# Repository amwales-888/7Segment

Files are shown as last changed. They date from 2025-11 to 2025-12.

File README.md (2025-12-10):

# 7Segment
Simple Large 7Segment Display

Who doesn't love big 7Segment displays?
Modelled the hardware in solidworks, printed on BambuLabs P1S. PCBs designed in KiCAD and boards manufactured by JLPCB.
The microcontroller I am using is a dsPIC33CK and it is interfaced to the WS2812 chips through DMA->SPI. It took quite a bit of fiddling to get the DMA->SPI working. 
</p>
For the clock I used a battery backed ds3102, 3 button's allow you to set the time and change the colors.
</p>
<table>
  <tr>
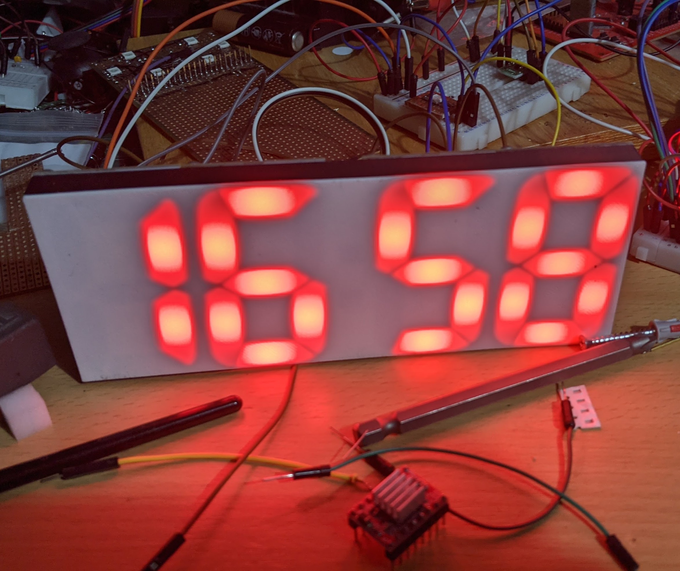
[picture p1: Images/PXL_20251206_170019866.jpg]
    <td> </td>
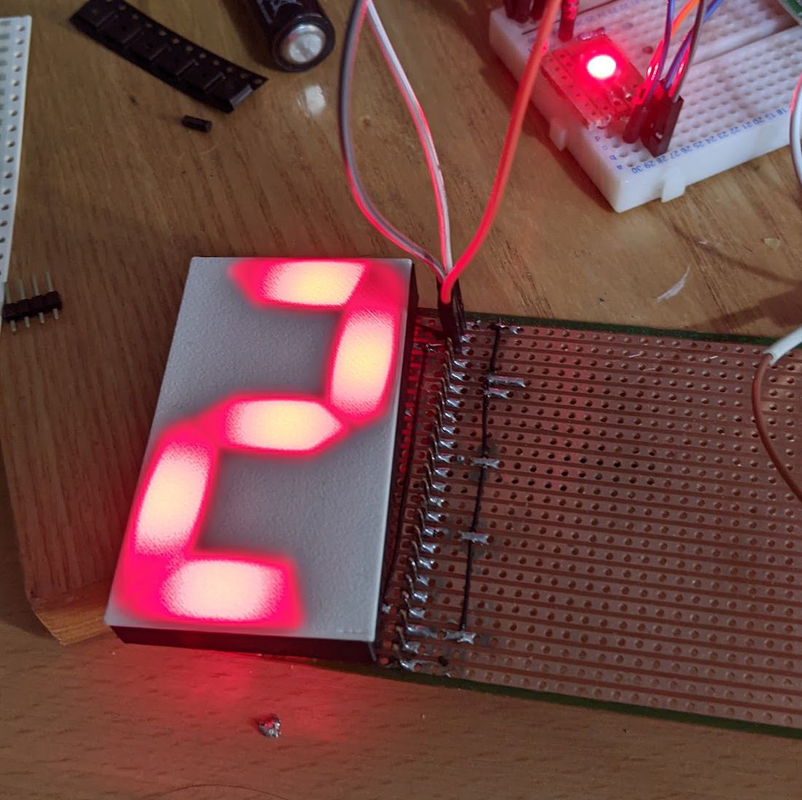
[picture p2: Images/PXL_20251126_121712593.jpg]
    <td> </td>
  </tr>
  <tr>
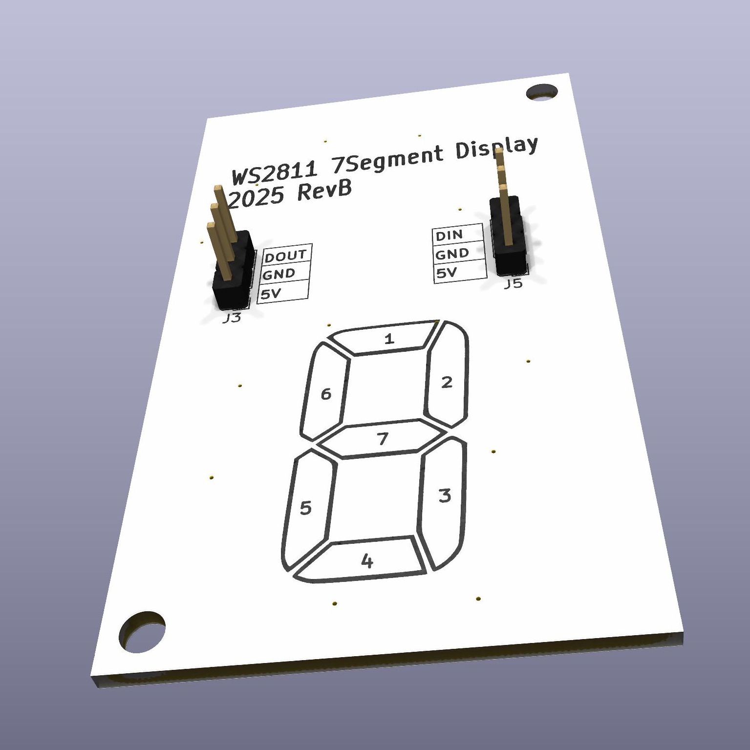
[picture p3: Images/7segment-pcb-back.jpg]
    <td> </td>
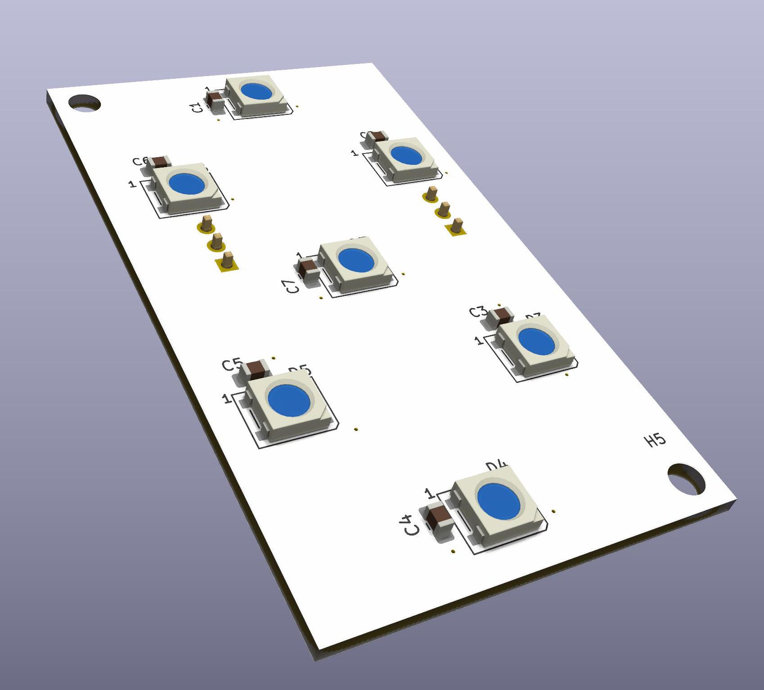
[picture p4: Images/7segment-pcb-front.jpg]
    <td> </td>
  </tr>
  <tr>
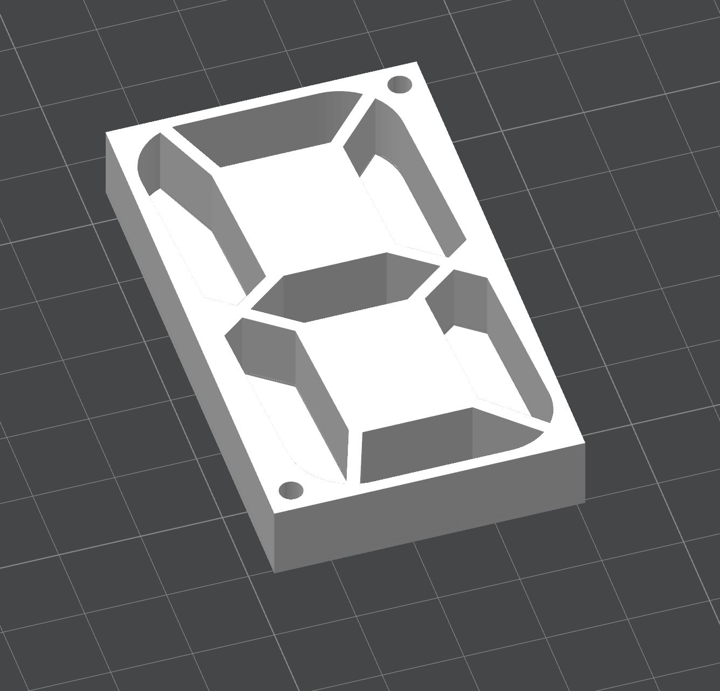
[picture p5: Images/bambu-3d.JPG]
    <td> </td>
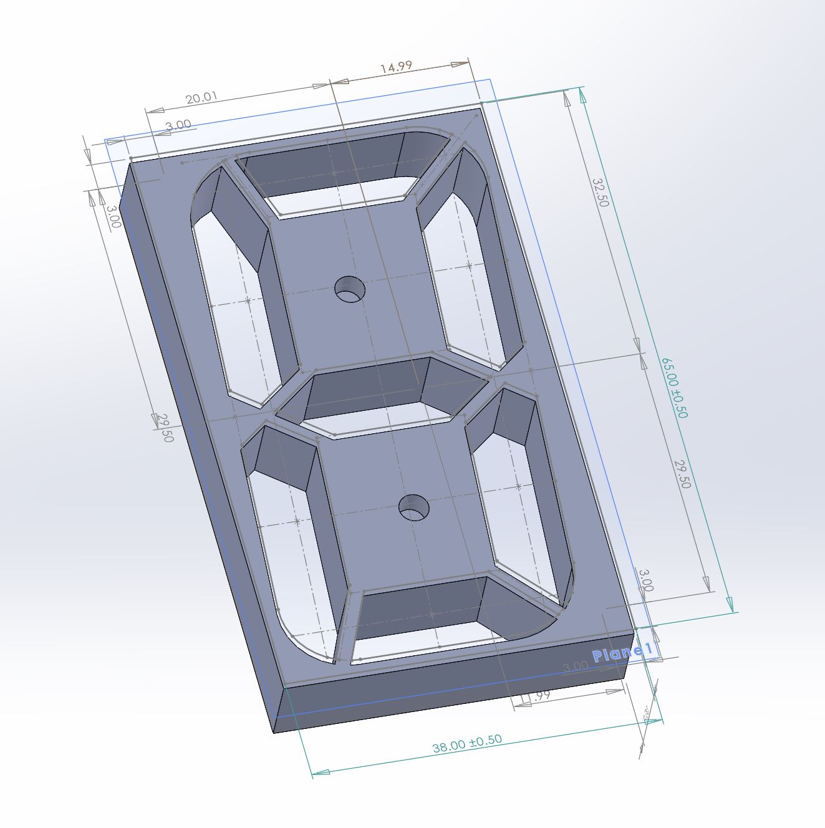
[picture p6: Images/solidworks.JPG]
    <td> </td>
  </tr>
</table>

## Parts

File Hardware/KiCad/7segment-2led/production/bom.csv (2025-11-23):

Designator | Footprint | Quantity | Value | LCSC Part #
C1, C2, C3, C4, C5, C6, C7 | 0805 | 7 | 0.1uF
D1, D2, D3, D4, D5, D6, D7 | LED_WS2812B_PLCC4_5.0x5.0mm_P3.2mm | 7 | WS2812B
J3, J5 | PinHeader_1x03_P2.54mm_Vertical | 2 | Conn_01x03

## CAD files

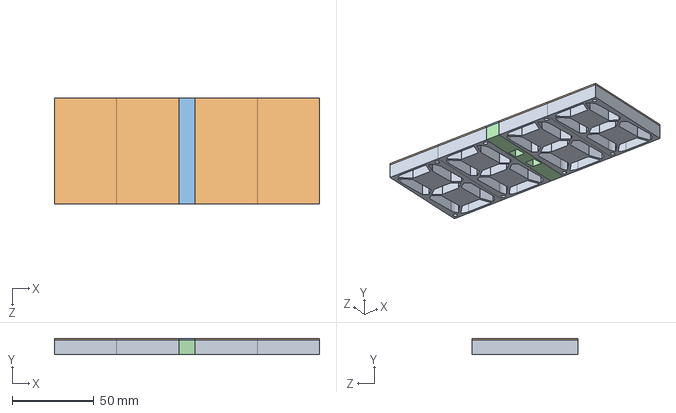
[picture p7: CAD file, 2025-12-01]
Hardware/CAD/7segment-assembley.STEP
162.0 x 10.0 x 65.0 mm
led-segment-p4 x 4

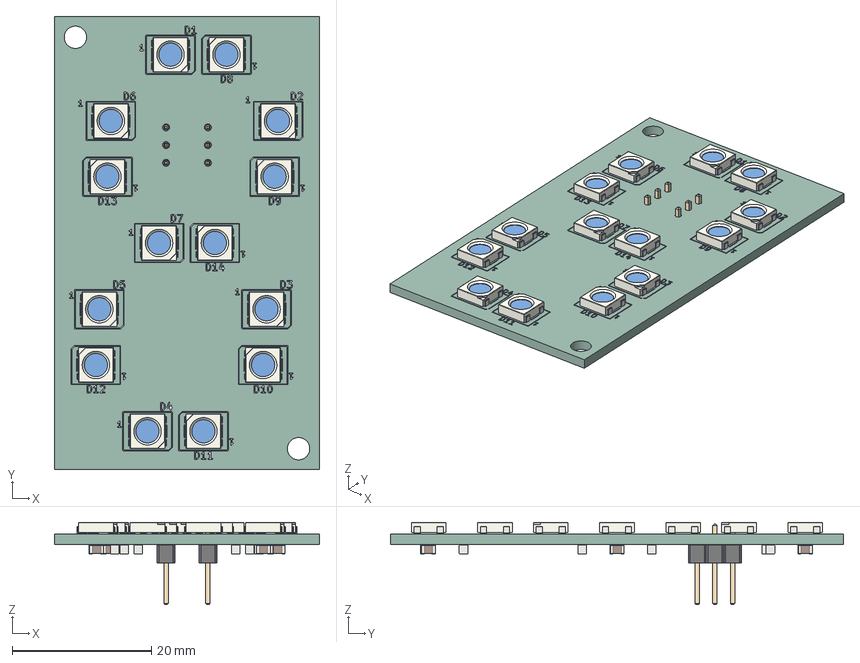
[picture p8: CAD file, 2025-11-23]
Hardware/KiCad/7segment-2led/7segment-2led.step
38.0 x 65.0 x 11.8 mm
LED_WS2812B_PLCC4_5.0x5.0mm_P3.2mm x 14
C_0805_2012Metric x 14
PinHeader_1x03_P2.54mm_Vertical x 2
7segment_silkscreen x 2
7segment_PCB

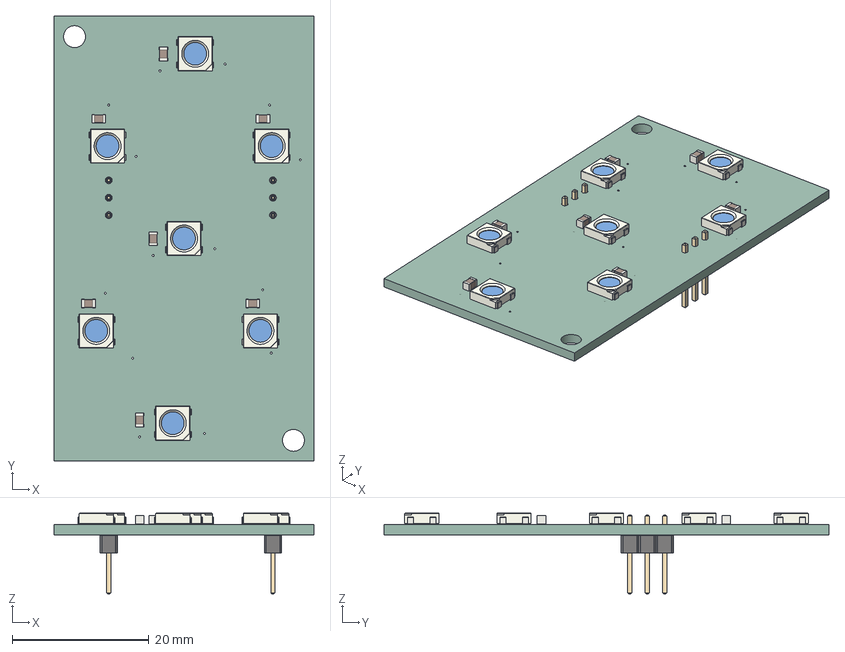
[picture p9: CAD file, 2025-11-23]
Hardware/KiCad/7segment/7segment.step
38.0 x 65.0 x 11.8 mm
LED_WS2812B_PLCC4_5.0x5.0mm_P3.2mm x 7
C_0805_2012Metric x 7
PinHeader_1x03_P2.54mm_Vertical x 2
7segment_PCB

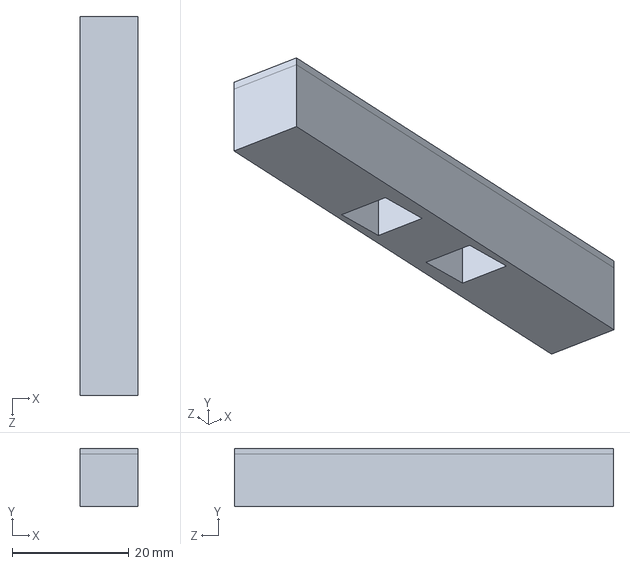
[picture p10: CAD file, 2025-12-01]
Hardware/CAD/Part1.SLDPRT
10.0 x 10.0 x 65.0 mm

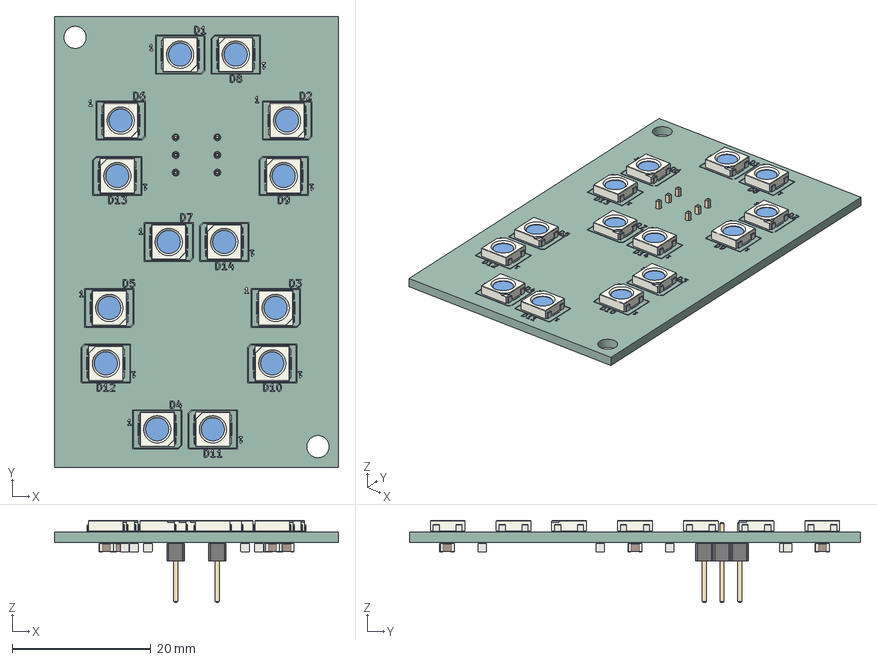
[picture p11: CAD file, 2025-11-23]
Hardware/KiCad/7segment-2led/7segment.step
41.0 x 65.0 x 11.8 mm
LED_WS2812B_PLCC4_5.0x5.0mm_P3.2mm x 14
C_0805_2012Metric x 14
PinHeader_1x03_P2.54mm_Vertical x 2
7segment_silkscreen x 2
7segment_PCB

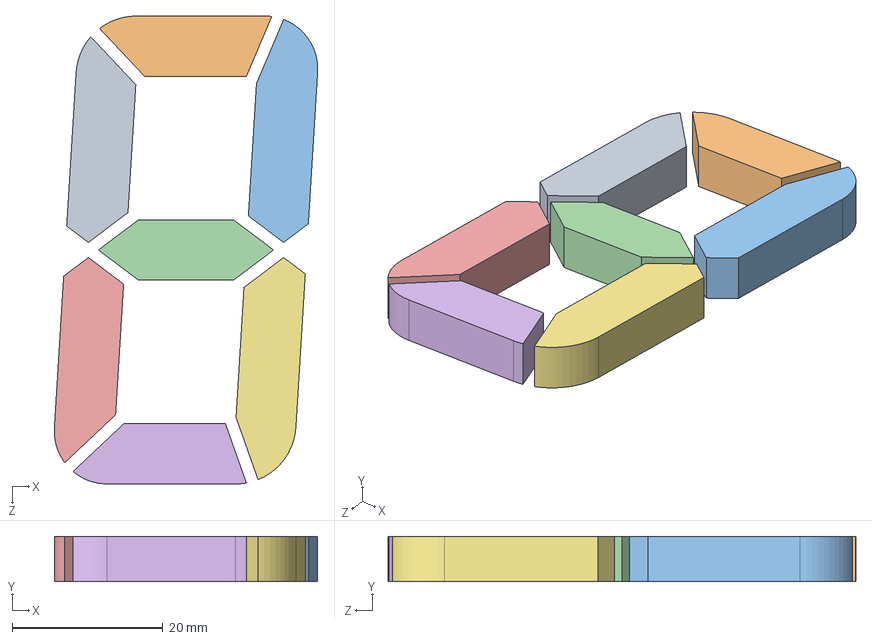
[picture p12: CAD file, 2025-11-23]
Hardware/CAD/led-segment-insert-p4.STEP
34.9 x 6.00 x 62.0 mm

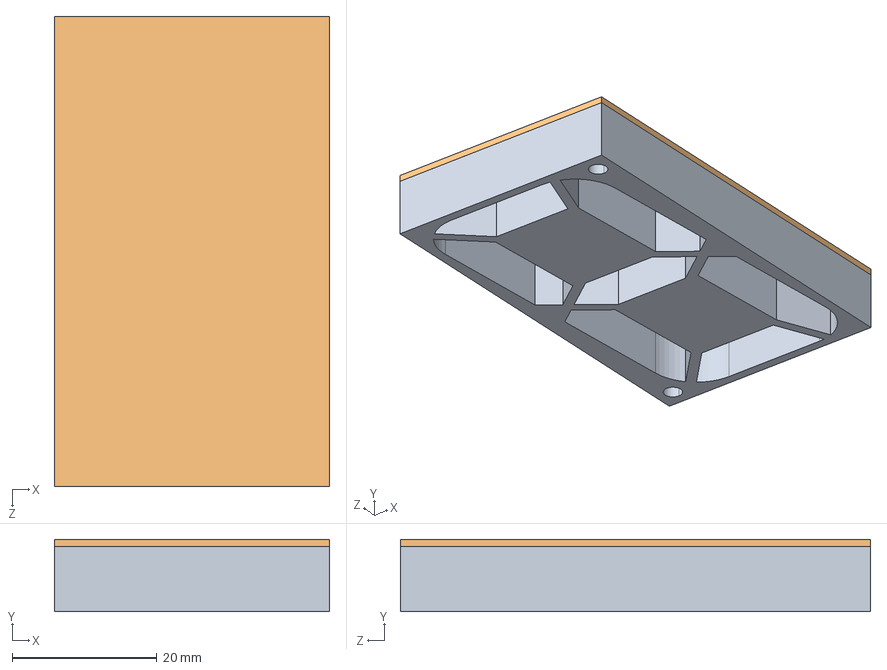
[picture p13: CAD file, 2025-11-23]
Hardware/CAD/led-segment-p4.STEP
38.0 x 10.0 x 65.0 mm

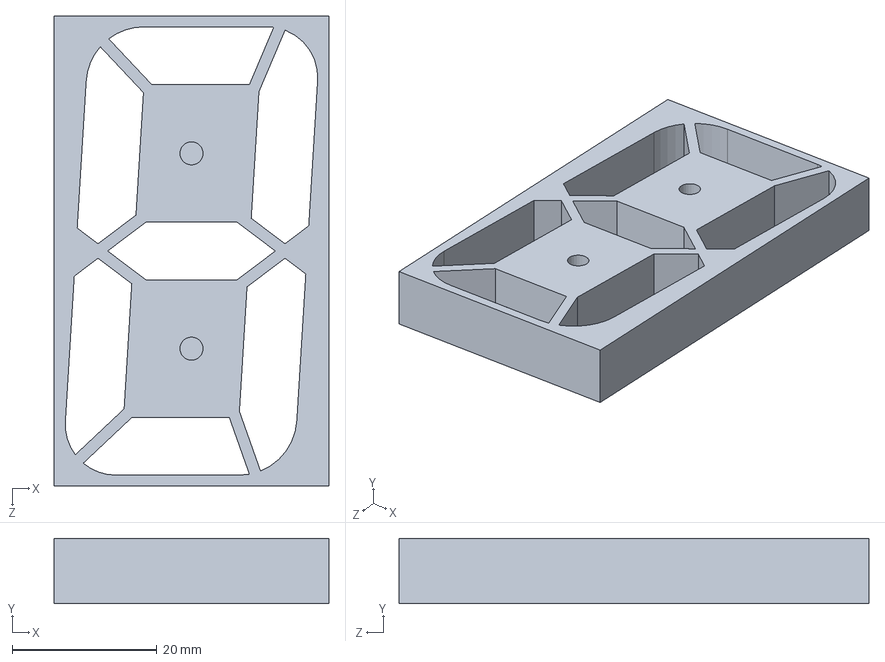
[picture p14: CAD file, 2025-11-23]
Hardware/CAD/led-segment-2led-p4.SLDPRT
38.0 x 9.00 x 65.0 mm

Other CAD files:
Hardware/CAD/led-segment-p3.SLDPRT
Hardware/CAD/7segment-assembley.SLDASM
Hardware/CAD/led-segment-insert-p4.SLDPRT
Hardware/CAD/led-segment-p4.SLDPRT

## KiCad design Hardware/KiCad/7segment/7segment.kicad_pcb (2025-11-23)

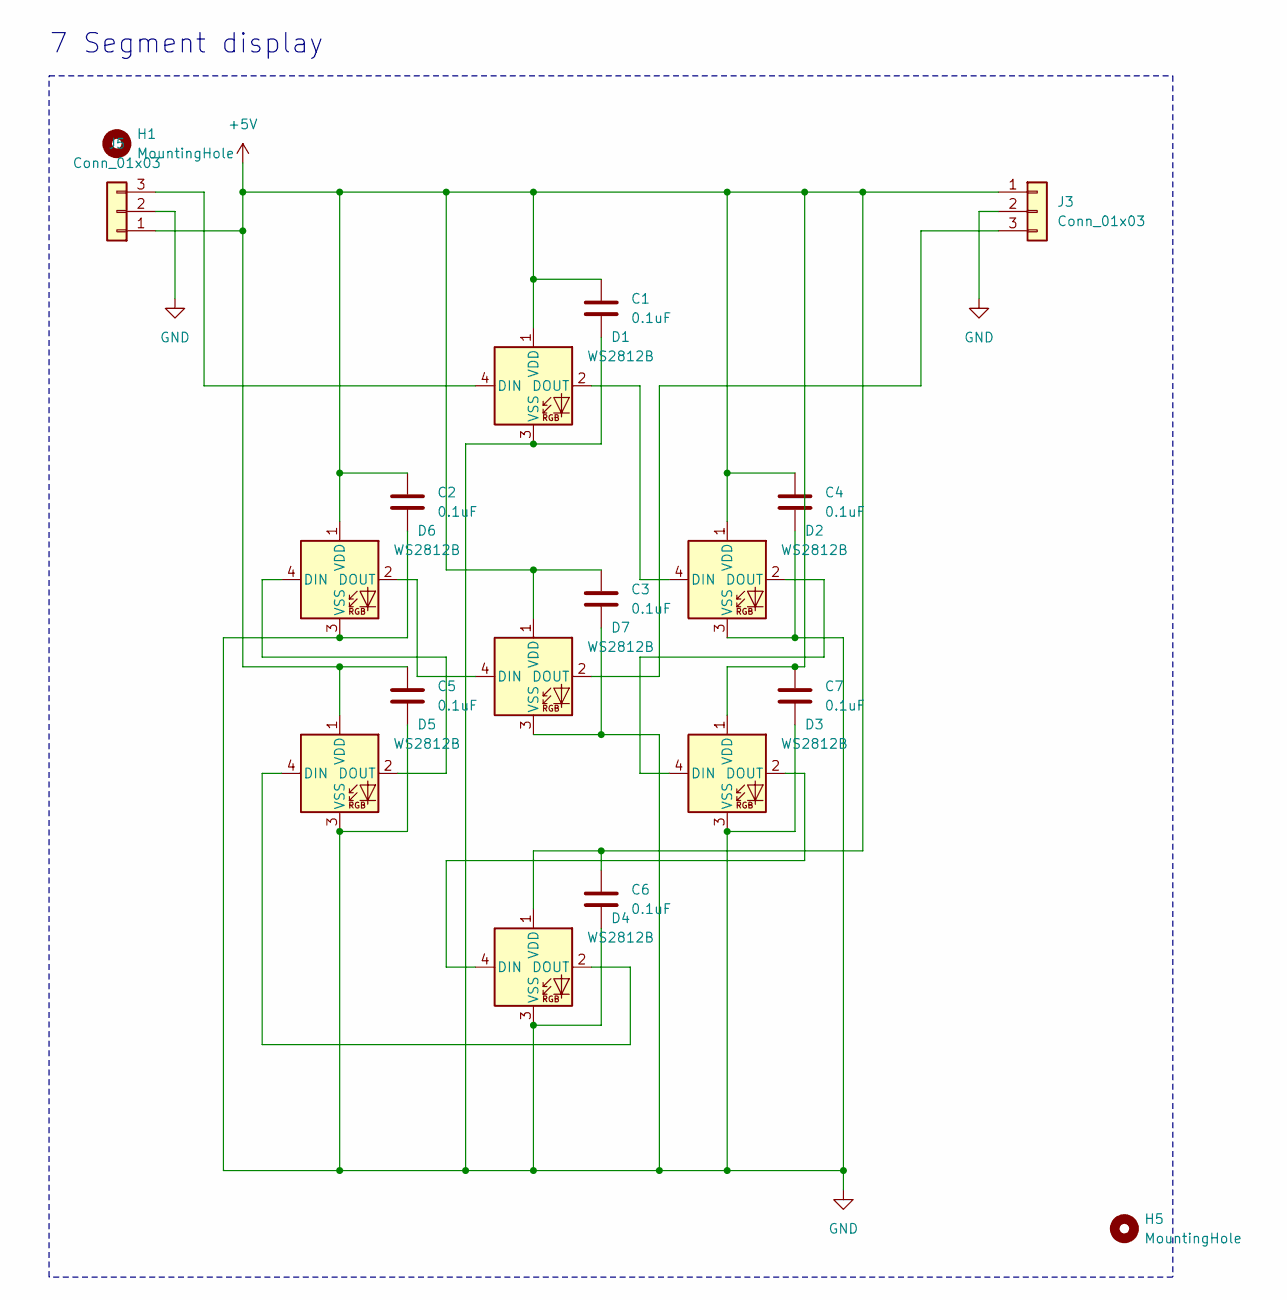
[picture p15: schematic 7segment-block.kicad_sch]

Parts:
C1, C2, C3, C4, C5, C6, C7: 0.1uF; C_0805_2012Metric_Pad1.18x1.45mm_HandSolder
D1, D2, D3, D4, D5, D6, D7: WS2812B; LED_WS2812B_PLCC4_5.0x5.0mm_P3.2mm
H1, H5: MountingHole; MountingHole_3.2mm_M3
J3, J5: Conn_01x03; PinHeader_1x03_P2.54mm_Vertical

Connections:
+5V: C1.1, C2.1, C3.1, C4.1, C5.1, C6.1, C7.1, D1.1 (VDD), D2.1 (VDD), D3.1 (VDD), D4.1 (VDD), D5.1 (VDD), D6.1 (VDD), D7.1 (VDD), J3.1, J5.1
GND: C1.2, C2.2, C3.2, C4.2, C5.2, C6.2, C7.2, D1.3 (VSS), D2.3 (VSS), D3.3 (VSS), D4.3 (VSS), D5.3 (VSS), D6.3 (VSS), D7.3 (VSS), J3.2, J5.2
unnamed: D1.4 (DIN), J5.3
unnamed: D1.2 (DOUT), D2.4 (DIN)
unnamed: D2.2 (DOUT), D3.4 (DIN)
unnamed: D3.2 (DOUT), D4.4 (DIN)
unnamed: D4.2 (DOUT), D5.4 (DIN)
unnamed: D5.2 (DOUT), D6.4 (DIN)
unnamed: D6.2 (DOUT), D7.4 (DIN)
unnamed: D7.2 (DOUT), J3.3

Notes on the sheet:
7 Segment display

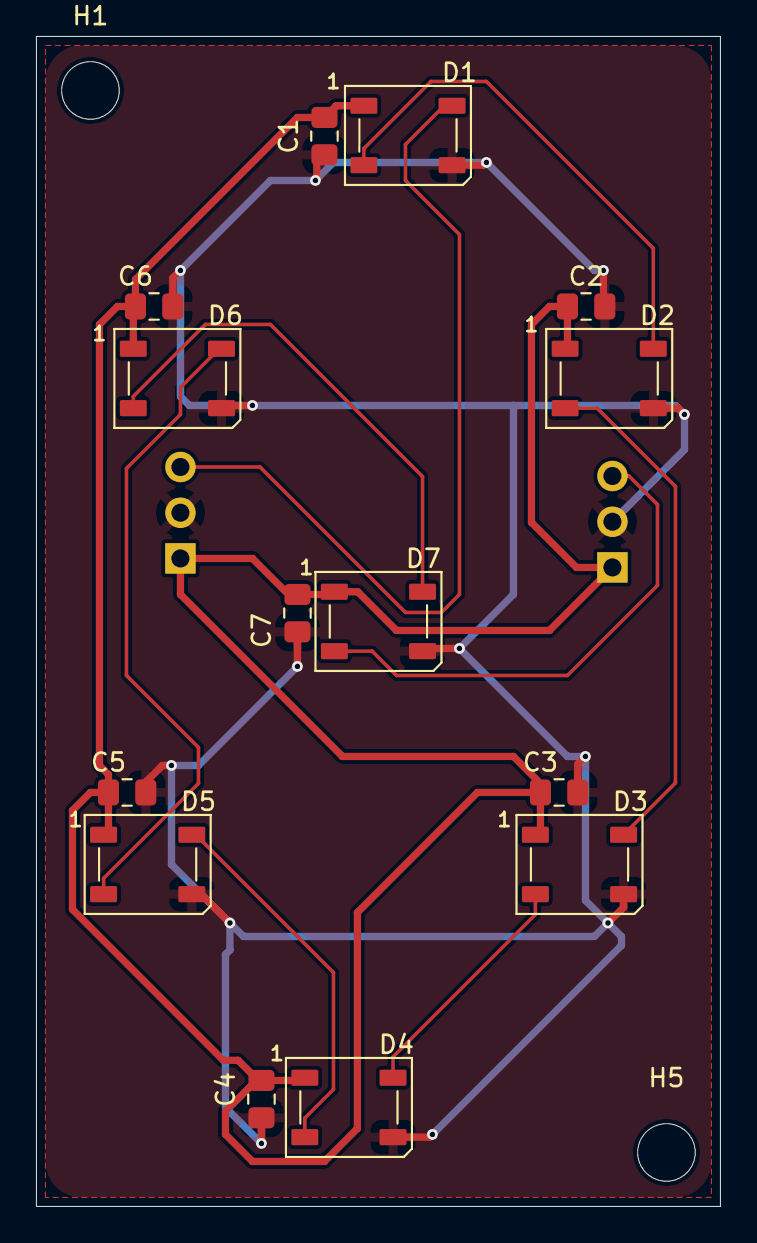
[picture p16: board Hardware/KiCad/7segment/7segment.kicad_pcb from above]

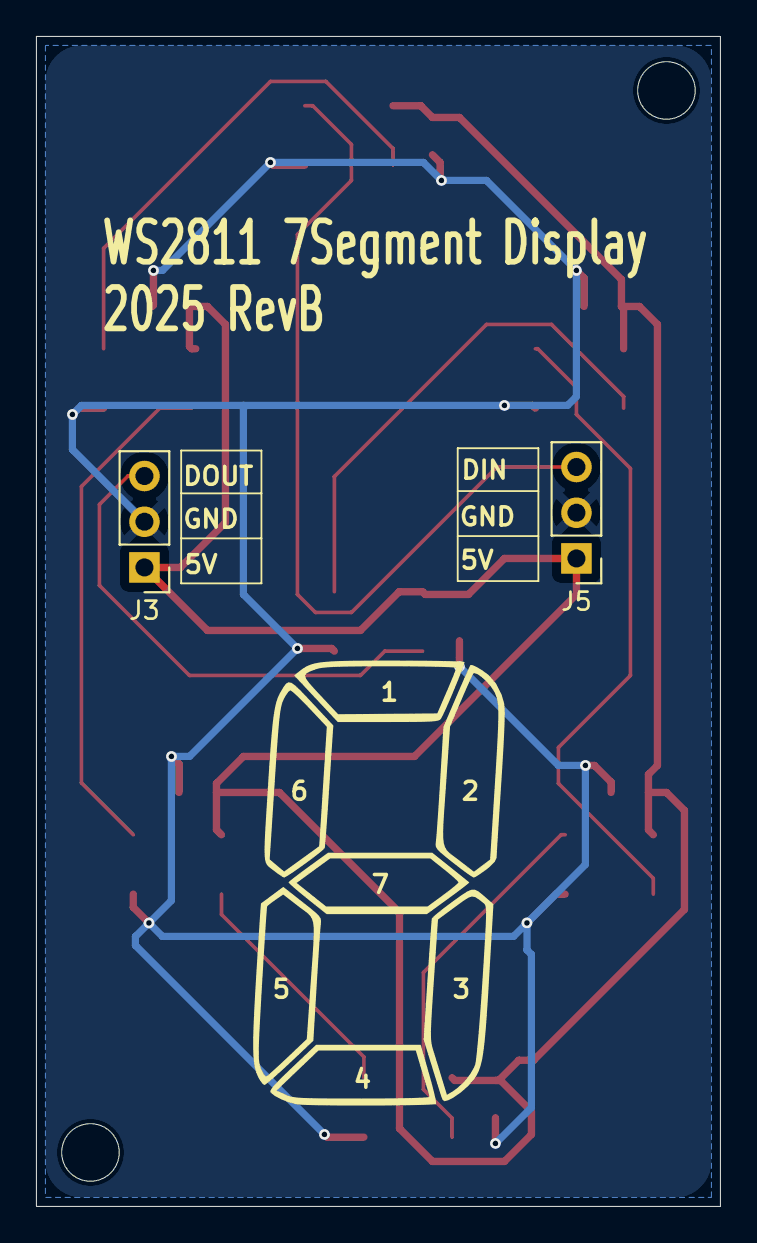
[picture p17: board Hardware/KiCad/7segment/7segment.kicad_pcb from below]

Board: 2 copper layers, 38.0 x 65.0 mm, 18 parts (2 on the bottom side), 10 nets.

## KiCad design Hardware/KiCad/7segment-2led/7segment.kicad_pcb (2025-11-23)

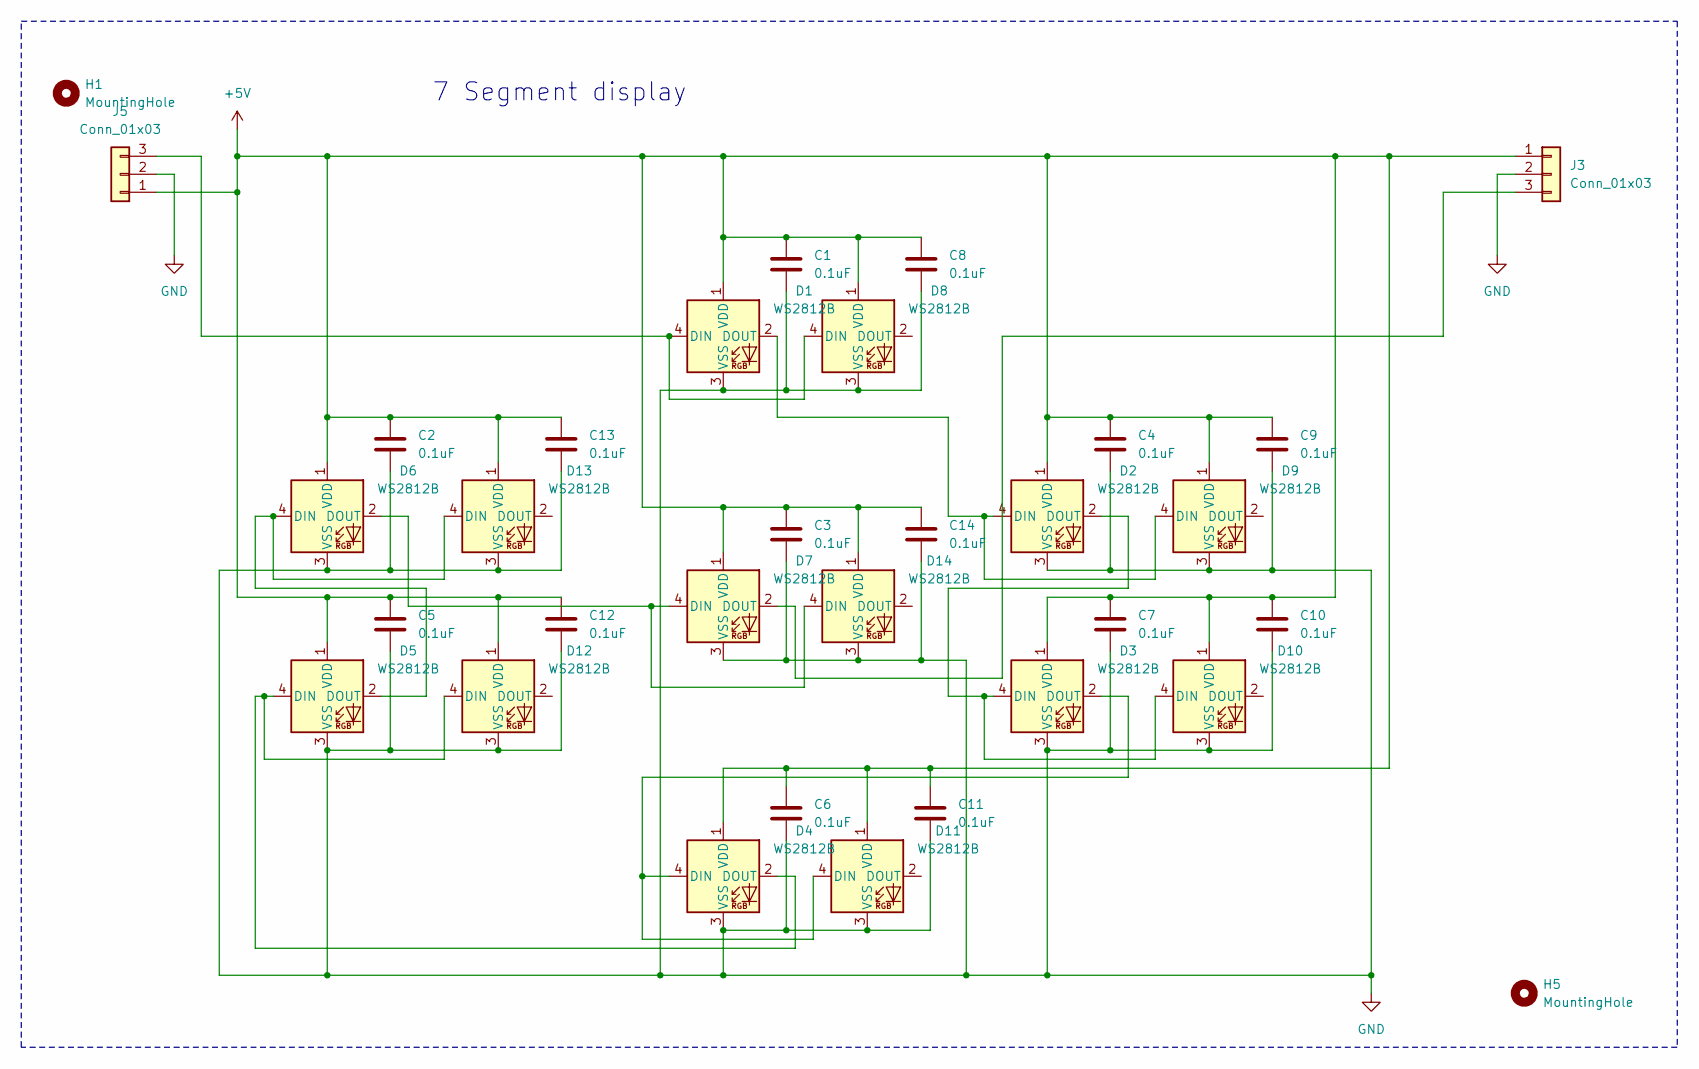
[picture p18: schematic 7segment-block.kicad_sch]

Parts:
C1, C2, C3, C4, C5, C6, C7, C8, C9, C10, C11, C12, C13, C14: 0.1uF; C_0805_2012Metric_Pad1.18x1.45mm_HandSolder
D1, D2, D3, D4, D5, D6, D7, D8, D9, D10, D11, D12, D13, D14: WS2812B; LED_WS2812B_PLCC4_5.0x5.0mm_P3.2mm
H1, H5: MountingHole; MountingHole_3.2mm_M3
J3, J5: Conn_01x03; PinHeader_1x03_P2.54mm_Vertical

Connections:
+5V: C1.1, C2.1, C3.1, C4.1, C5.1, C6.1, C7.1, C8.1, C9.1, C10.1, C11.1, C12.1, C13.1, C14.1, D1.1 (VDD), D2.1 (VDD), D3.1 (VDD), D4.1 (VDD), D5.1 (VDD), D6.1 (VDD), D7.1 (VDD), D8.1 (VDD), D9.1 (VDD), D10.1 (VDD), D11.1 (VDD), D12.1 (VDD), D13.1 (VDD), D14.1 (VDD), J3.1, J5.1
GND: C1.2, C2.2, C3.2, C4.2, C5.2, C6.2, C7.2, C8.2, C9.2, C10.2, C11.2, C12.2, C13.2, C14.2, D1.3 (VSS), D2.3 (VSS), D3.3 (VSS), D4.3 (VSS), D5.3 (VSS), D6.3 (VSS), D7.3 (VSS), D8.3 (VSS), D9.3 (VSS), D10.3 (VSS), D11.3 (VSS), D12.3 (VSS), D13.3 (VSS), D14.3 (VSS), J3.2, J5.2
unnamed: D1.4 (DIN), D8.4 (DIN), J5.3
unnamed: D1.2 (DOUT), D2.4 (DIN), D9.4 (DIN)
unnamed: D7.2 (DOUT), J3.3
unnamed: D2.2 (DOUT), D3.4 (DIN), D10.4 (DIN)
unnamed: D3.2 (DOUT), D4.4 (DIN), D11.4 (DIN)
unnamed: D4.2 (DOUT), D5.4 (DIN), D12.4 (DIN)
unnamed: D5.2 (DOUT), D6.4 (DIN), D13.4 (DIN)
unnamed: D6.2 (DOUT), D7.4 (DIN), D14.4 (DIN)

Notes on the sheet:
7 Segment display

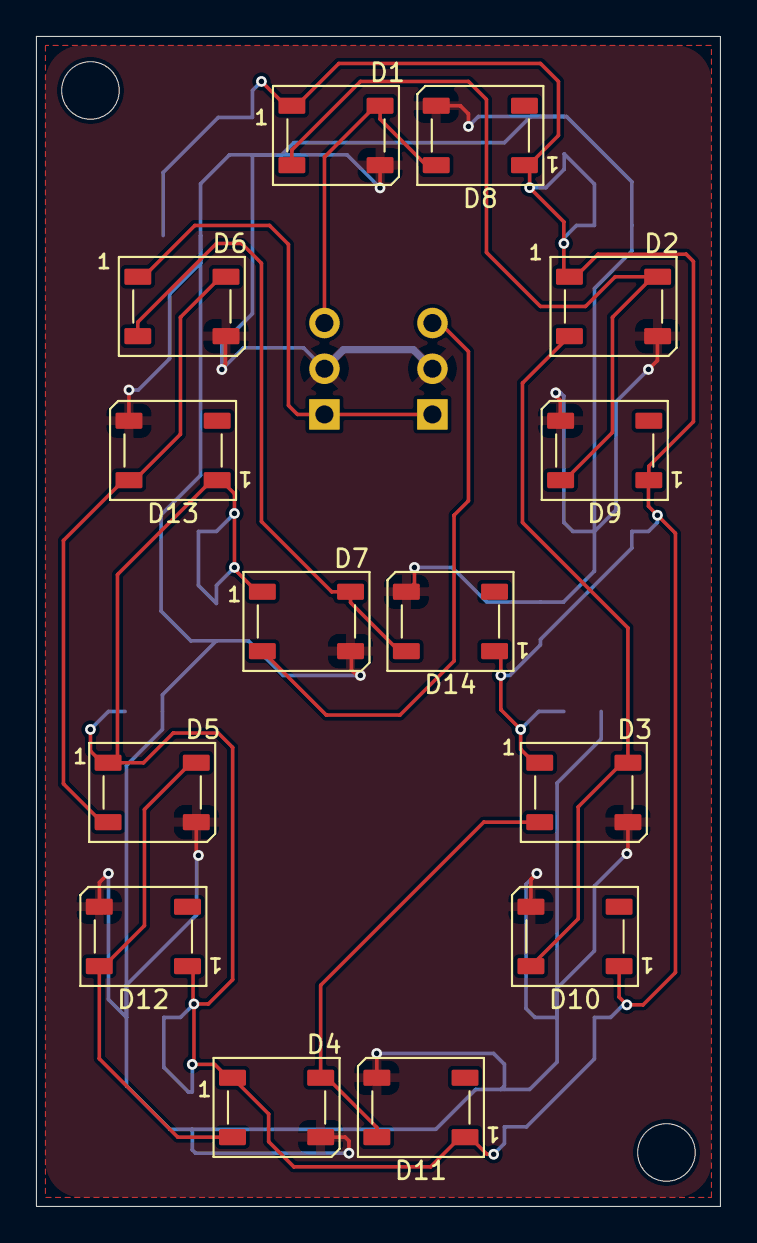
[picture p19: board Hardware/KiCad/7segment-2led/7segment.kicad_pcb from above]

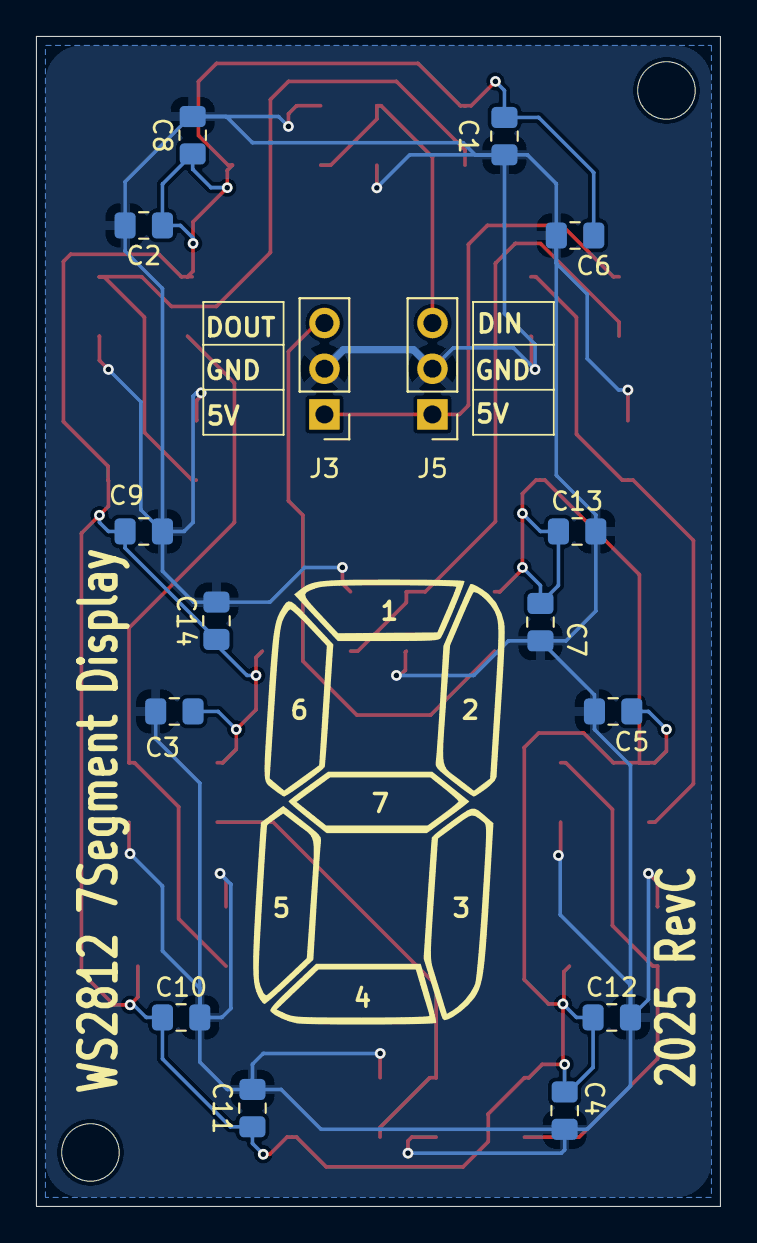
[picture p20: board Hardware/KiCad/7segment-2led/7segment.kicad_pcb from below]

Board: 2 copper layers, 38.0 x 65.0 mm, 32 parts (16 on the bottom side), 10 nets.

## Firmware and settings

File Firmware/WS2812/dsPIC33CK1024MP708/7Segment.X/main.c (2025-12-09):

/*
© [2025] Microchip Technology Inc. and its subsidiaries.

    Subject to your compliance with these terms, you may use Microchip 
    software and any derivatives exclusively with Microchip products. 
    You are responsible for complying with 3rd party license terms  
    applicable to your use of 3rd party software (including open source  
    software) that may accompany Microchip software. SOFTWARE IS ?AS IS.? 
    NO WARRANTIES, WHETHER EXPRESS, IMPLIED OR STATUTORY, APPLY TO THIS 
    SOFTWARE, INCLUDING ANY IMPLIED WARRANTIES OF NON-INFRINGEMENT,  
    MERCHANTABILITY, OR FITNESS FOR A PARTICULAR PURPOSE. IN NO EVENT 
    WILL MICROCHIP BE LIABLE FOR ANY INDIRECT, SPECIAL, PUNITIVE, 
    INCIDENTAL OR CONSEQUENTIAL LOSS, DAMAGE, COST OR EXPENSE OF ANY 
    KIND WHATSOEVER RELATED TO THE SOFTWARE, HOWEVER CAUSED, EVEN IF 
    MICROCHIP HAS BEEN ADVISED OF THE POSSIBILITY OR THE DAMAGES ARE 
    FORESEEABLE. TO THE FULLEST EXTENT ALLOWED BY LAW, MICROCHIP?S 
    TOTAL LIABILITY ON ALL CLAIMS RELATED TO THE SOFTWARE WILL NOT 
    EXCEED AMOUNT OF FEES, IF ANY, YOU PAID DIRECTLY TO MICROCHIP FOR 
    THIS SOFTWARE.
*/


#include "mcc_generated_files/system/system.h"
#include "mcc_generated_files/system/pins.h"
#include "mcc_generated_files/timer/delay.h"

#include <stdint.h>
#include <stdbool.h>

#include "pack.h"
#include "ws2812.h"
#include "segment.h"
#include "ds1302.h"
#include "scheduler.h"
#include "button.h"
#include "mcc_generated_files/timer/tmr1.h"

#define BUTTONGPIOID0 0
#define BUTTONGPIOID1 1
#define BUTTONGPIOID2 2

/*    Main application
*/

static void buttonDebounce(void *data);
static void buttonPoll(void *data);
static void segmentUpdate(void *data);
static void rttcUpdate(void *data);
static void segmentBlink(void *data);


static PROCESSALLOCATE(buttonDebounceProcess,       DEBOUNCE_INTEGRATOR_DELAYMS,  buttonDebounce,       (void *)0 );
static PROCESSALLOCATE(buttonPollProcess,           DEBOUNCE_DELAYMS,             buttonPoll,           (void *)0 );
static PROCESSALLOCATE(segmentUpdateProcess,        100,                          segmentUpdate,        (void *)0 );
static PROCESSALLOCATE(rttcUpdateProcess,           250,                          rttcUpdate,           (void *)0 );
static PROCESSALLOCATE(segmentBlinkProcess,         500,                          segmentBlink,         (void *)0 );


static uint8_t segmentValues[] = { 0, 0, 0, 0 };
static struct dateTime_s dt;

enum clockState_e {
    
    showTime=0,
    setHours,
    setMinutes,    
    setColor,
};


#define MAXCOLOR 4

enum clockColor_e {
    
    colorRed=0,
    colorGreen,
    colorBlue,
    colorWhite,
};




static bool segmentHourOff;
static bool segmentMinuteOff;
static enum clockState_e clockState = showTime;
static enum clockColor_e clockColor = colorRed;

static void 
buttonDebounce(void *data) {
    
    buttonUpdateIntegrator();
}

static void 
buttonPoll(void *data) {

    buttonUpdate();
}

static void 
buttonCallback0(uint8_t id, enum buttonState_e state, void *data) {

    switch (clockState) {
        case showTime: {
            
            if (state == BUTTONHELD) {  
                
                uint16_t count = buttonGetCount(id);
                if (BUTTONCOUNTTOMS(count) >= 3000) {
                    processDisable(&rttcUpdateProcess);
                    clockState = setHours;
                }
            }                
            break;
        }        
        case setHours: {
            
            if (state == BUTTONPRESSED) {           
                clockState = setMinutes;
            }    
            break;
        }
        case setMinutes: {
            
            if (state == BUTTONPRESSED) {           
                
                ds1302WriteTime(&dt);                
                processEnable(&rttcUpdateProcess);                
                clockState = showTime;
            }    
            break;
        }            
        case setColor: {
            
            if (state == BUTTONPRESSED) {           
            
                if (clockColor == 0) {
                    clockColor = MAXCOLOR-1;
                } else {
                    clockColor--;
                }
            }                        
            break;
        }
        
        default: {
            break;
        }
    }
}

static void 
buttonCallback1(uint8_t id, enum buttonState_e state, void *data) {

    switch (clockState) {
        case showTime: {
            
            if (state == BUTTONHELD) {  
                
                uint16_t count = buttonGetCount(id);
                if (BUTTONCOUNTTOMS(count) >= 3000) {
                    clockState = setColor;
                }
            }                
            break;
        }        
        case setHours: {

            if (state == BUTTONPRESSED) {                           
                dt.hour++;
                if (dt.hour == 24) {
                    dt.hour = 0;
                }
            }            
            break;
        }
        case setMinutes: {
            
            if (state == BUTTONPRESSED) {                           
                dt.minute++;
                if (dt.minute == 60) {
                    dt.minute = 0;
                }
            }
            break;
        }
        case setColor: {

            if (state == BUTTONPRESSED) {         
                clockState = showTime;
            }
            break;
        }
        default: {
            break;
        }            
    }
}

static void 
buttonCallback2(uint8_t id, enum buttonState_e state, void *data) {

    switch (clockState) {
        case setHours: {

            if (state == BUTTONPRESSED) {                           
                dt.hour--;
                if (dt.hour == (uint8_t)-1) {
                    dt.hour = 23;
                }
            }            
            break;
        }
        case setMinutes: {
            
            if (state == BUTTONPRESSED) {                           
                dt.minute--;
                if (dt.minute == (uint8_t)-1) {
                    dt.minute = 59;
                }
            }
            break;
        }
        case setColor: {
            
            if (state == BUTTONPRESSED) {           
            
                if (clockColor == MAXCOLOR-1) {
                    clockColor = 0;
                } else {
                    clockColor++;
                }
            }                        
            break;
        }
        default: {
            break;
        }            
    }
}

void TMR1_TimeoutCallback( void ) { 

    /* Callback from TMR1 Interrupt */
    
    schedulerIncrementTicks();
}



static void 
rttcUpdate(void *data) {

    ds1302ReadTime(&dt);
}

static void 
segmentBlink(void *data) {

    if ((clockState == setHours) || (clockState == setColor)) {        
        segmentHourOff ^= 1;        
    } else {
        segmentHourOff = 0;        
    }

    if ((clockState == setMinutes) || (clockState == setColor)) {
        segmentMinuteOff ^= 1;        
    } else {
        segmentMinuteOff = 0;                
    }
}


static void 
segmentUpdate(void *data) {

        
    uint8_t hh, hl, mh, ml;

    hh = dt.hour   / 10;
    hl = dt.hour  % 10;

    mh = dt.minute / 10;
    ml = dt.minute % 10;

    /* Populate ALL 4 7Segment displays 
     */            
    
    if (segmentHourOff) {
        
        segmentValues[0] = SEGMENTVALUEOFF;
        segmentValues[1] = SEGMENTVALUEOFF;

    } else {
        
        segmentValues[0] = hh;
        segmentValues[1] = hl;
    }
    
    if (segmentMinuteOff) {
        
        segmentValues[2] = SEGMENTVALUEOFF;
        segmentValues[3] = SEGMENTVALUEOFF;

    } else {
        
        segmentValues[2] = mh;
        segmentValues[3] = ml;
    }
    
    switch (clockColor) {
        case colorRed:
            segmentsOut(segmentValues, 4, 0xff, 0, 0 );
            break;
        case colorGreen:
            segmentsOut(segmentValues, 4, 0, 0xff, 0 );
            break;
        case colorBlue:
            segmentsOut(segmentValues, 4, 0, 0, 0xff );
            break;
        case colorWhite:
            segmentsOut(segmentValues, 4, 0xff, 0xff, 0xff );
            break;
    }
}

int main(void)
{
    uint8_t clockStartCount = 0;
    
    SYSTEM_Initialize();
    
    LED0_SetHigh();
       
    ws2812Initialize();
    
    ds1302Initialize();
    
    while (!ds1302IsRunning()) {
        ds1302Start();
        DELAY_milliseconds(250);
    } 
    
    schedulerProcessAdd(&buttonDebounceProcess);
    schedulerProcessAdd(&buttonPollProcess);
    schedulerProcessAdd(&segmentUpdateProcess);
    schedulerProcessAdd(&rttcUpdateProcess);
    schedulerProcessAdd(&segmentBlinkProcess);
                
    buttonEnable(BUTTONGPIOID0, buttonCallback0, (void *)0, 0);
    buttonEnable(BUTTONGPIOID1, buttonCallback1, (void *)0, 0);
    buttonEnable(BUTTONGPIOID2, buttonCallback2, (void *)0, 0);
    
    TMR1_Start();
    
    while(1) {

        schedulerRun();
    }
}

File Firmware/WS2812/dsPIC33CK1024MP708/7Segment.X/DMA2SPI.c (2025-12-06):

/*
 *  Copyright (c) 2025 Angelo Masci
 *
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
 */

/* The DMA->SPI was inspired by the work done by Broadwell Consulting and 
 * the youtube video found at https://www.youtube.com/watch?v=_HJepzYc6_0
 * the w2812 code was released under an MIT licensed and inititally used as
 * a reference to debug the DMA->SPI code in this file.
 * 
 * The dsPIC33CK1024MP708 used here requires that a second DMA channel used
 * to read from the SPI, failing to do this causes the SPI to stall.
 * I am using a 300ns SPI period and 3 bits for each of bit on the WS2812.
 * 
 * The peripheral clock is running at 100Mhz and a BRG value of 16 is used to 
 * achive this.
 * 
 *  |SPI  |SPI  |SPI  |
 *  |Bit  |Bit  |Bit  |
 *  |300ns|300ns|300ns|
 * 
 *  +-----+
 *  |     |              WS2812 0 Bit
 *  |     +-----+-----+
 * 
 *  +-----+-----+
 *  |           |        WS2812 1 Bit
 *  |           +-----+
 *  
 * These value fall within the specifications of the WS2812 datasheet I am using 
 * found at https://github.com/amwales-888/7Segment/blob/main/Hardware/KiCad/Docs/ws2812B-C22461793.pdf
 * 
 *            Time in ns
 *            Min Typ Max
 *  0 High    200 300 400
 *  1 High    550 600 1200
 *  0 Low     550 600 1200
 *  1 Low     200 300 400
 * 
 *  Cycle     900 -   -
 * 
 * Our cycle time is 3x300 ns
 * and the other transitions we use are the typical spec value of 300 and 600
 * 
 * The bits are packed into a byte buffer, 5 WS2812 bits require 15 SPI Bits
 * and 2 packed Bytes in the DMA buffer.
 * 
 * As of Nov 2025 I believe that the Serial Wombat code could make significant 
 * RAM savings by changing it to use a 375ns period and using 3bit packing
 */

#include "mcc_generated_files/system/system.h"
#include "mcc_generated_files/system/pins.h"
#include "mcc_generated_files/timer/delay.h"
#include "mcc_generated_files/system/clock.h"

#include "pack.h"

#include <stdint.h>
#include <stdbool.h>

static void DMAInitialize(void) {

    DMACONbits.DMAEN=1;  // Enable DMA
    DMACONbits.PRSSEL=1; // 1 => Round robin scheme
    DMAL=0x1000;         // Lower DMA Bounds
    DMAH=0xFFFF;         // Upper DMA Bounds
}

static void SPI1Initialize (void)
{
    
    // Configure Peripheral Pin Select for SPI
        
    __builtin_write_RPCON(0x0000); // unlock PPS

    RPOR1bits.RP34R = 0x0005U;  //RB2->SPI1:SDO1;

     __builtin_write_RPCON(0x0800); // lock PPS    
    
    
    // Disable SPI1 so it can be configured
    SPI1CON1Lbits.SPIEN = 0x0U;    

    // SPIEN disabled; DISSDO disabled; MCLKEN FOSC/2; CKP Idle:Low, Active:High; SSEN disabled; MSTEN Host; MODE16 disabled; SMP Middle; DISSCK disabled; SPIFE Frame Sync pulse precedes; CKE Idle to Active; MODE32 disabled; SPISIDL disabled; ENHBUF enabled; DISSDI disabled; 
    SPI1CON1L = 0x21U;
    
    // AUDEN disabled; FRMEN disabled; AUDMOD I2S; FRMSYPW One clock wide; AUDMONO stereo; FRMCNT 0x0; MSSEN disabled; FRMPOL disabled; IGNROV disabled; SPISGNEXT not sign-extended; FRMSYNC disabled; URDTEN disabled; IGNTUR disabled; 
    SPI1CON1H = 0x0U;
    SPI1CON1Hbits.IGNROV = 0;

    // WLENGTH disabled; 
    SPI1CON2L = 0x0U;

    // SPIROV disabled; FRMERR disabled; 
    SPI1STATL = 0x0U;
    SPI1STATH = 0x0U;

    // Baud Rate Generator SPIBRGL divisor 1; 
    // Baud Rate = FP / ( 2 * (SPIxBRG + 1))
    //
    // CLOCK_PeripheralFrequencyGet() = 100000000
    //
    // 100000000 / (2 * (14+1)) = 3333333 Hz
    // 1 / 3333333 = 0.0000003 s
    // 300 ns

//#if  ( CLOCK_PeripheralFrequencyGet() != 100000000UL )
//#error "Expect peripheral clock frequency was 100MHz, recalculate SPI1BRGL"
//#endif    
    
    SPI1BRGL = 0x0EU; // 300ns period
            
    // FRMERREN disabled; BUSYEN disabled; SPITUREN disabled; SRMTEN disabled; SPIROVEN disabled; SPIRBEN disabled; SPITBEN enabled; SPITBFEN disabled; SPIRBFEN enabled
    // SPITBEN enables Interrupt Events via SPITBE bit, SPIx transmit buffer empty generates an interrupt event
    // SPIRBFEN enables Interrupt Events via SPIRBF bit, SPIx receive buffer full generates an interrupt event    
    SPI1IMSKL = 0x9U;

    // RXWIEN disabled; RXMSK disabled; TXWIEN disabled; TXMSK disabled
    SPI1IMSKH = 0x0U;
           
    // SPIURDTL 0; 
    SPI1URDTL = 0x0U;
    // SPIURDTH 0; 
    SPI1URDTH = 0x0U;

    // Enable SPI1 so changes take affect
    SPI1CON1Lbits.SPIEN = 1U;    
}

void DMA2SPIInitialize(void) {
    
    DMAInitialize();
    SPI1Initialize();
}

bool DMA2SPIBusy(void) {
        
    return (DMACH0bits.CHEN != 0);
}

void DMA2SPIStart(uint8_t *buffer, size_t count) {

    static uint8_t dummy;         // Put the reasult of the SPI read here
        
    // Start the DMA Transfer

    /* Channel 1 reads from the SPI when there is data available to be read 
     * NOTE - Failing to do so will cause DMA to stall waiting for SPI read 
     * buffer to be emptied.
     */
    
    DMACH1bits.CHEN = 0; // Disable the channel so we can configure it
            
    DMACH1bits.SIZE    = 1; // 8bit mode
    DMACH1bits.RELOAD  = 1; // Reload
    DMACH1bits.TRMODE  = 3; // Continuous
    DMACH1bits.SAMODE  = 0; // Peripheral    
    DMACH1bits.DAMODE  = 0; // Destination Address remains unchanged
    DMAINT1bits.CHSEL  = 2; // SPI1 RX
    DMAINT1bits.DONEIF = 0; // Clear the interrupt completion flag
            
    /* Setup source, destination and count 
     */    
    DMASRC1 = (uint16_t)&SPI1BUFL;
    DMADST1 = (uint16_t)&dummy;
    DMACNT1 = 1;
    
    DMACH1bits.CHEN  = 1; // Enable the channel
    DMACH1bits.CHREQ = 1; // Force start

    /* Channel 0 writes to the SPI when there is space available to write
     */
    
    DMACH0bits.CHEN = 0; // Disable the channel so we can configure it
            
    DMACH0bits.SIZE    = 1; // 8bit mode
    DMACH0bits.TRMODE  = 0; // One-shot
    DMACH0bits.RELOAD  = 0; // Do not reload
    DMACH0bits.SAMODE  = 1; // Destination Address Post-increment
    DMACH0bits.DAMODE  = 0; // Peripheral                
    DMAINT0bits.CHSEL  = 3; // SPI1 TX
    DMAINT0bits.DONEIF = 0; // Clear the interrupt completion flag
    
    /* Setup source, destination and count 
     */    
//    DMASRC0 = (uint16_t)packDataGetBuffer();
    DMASRC0 = (uint16_t)buffer;
    DMADST0 = (uint16_t)&SPI1BUFL;
    DMACNT0 = count;

    DMACH0bits.CHEN  = 1; // Enable the channel
    DMACH0bits.CHREQ = 1; // Force start
}

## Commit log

2025-11-23 Initial checkin
    WS2812 7Segment display
    [7segment-2led.step, 7segment-assembley.SLDASM, 7segment-block.kicad_sch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]
2025-11-23 Add Demo
    Simple 7Segment led pattern increments from 0-9
2025-11-25 Fix SPI/DMA Issue
    Looks like the SPI would stall around 30bits, I replaced the count with 1 on the dma channel continuously reading from the SPI buffer and this fixed it.
    [main.c]
2025-12-01 Refactored code added ds1302 rttc support and made simple 4-7segment clock
    [7segment-assembley.SLDASM, 7segment-assembley.STEP, Part1.SLDPRT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]
2025-12-06 Working clock implementation
    Can now set the time with 3 buttons, hold the set button for 3-4 seconds, other buttons +- step through hours, minutes, blinks while setting
2025-12-06 Move DMS->SPI info about ws2812 to DMASPI file
2025-12-09 Added change color feature and fixed bug with missing write protect enable/disable when starting clock
    [main.c]
